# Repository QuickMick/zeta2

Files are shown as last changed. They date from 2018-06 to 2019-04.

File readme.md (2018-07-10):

streaming:
https://www.npmjs.com/package/h264-live-player
https://github.com/131/h264-live-player

old:https://www.npmjs.com/package/raspivid-stream

fan: 0.33 a
GY-88: 0.3 mA

pin input draw (zero position): 0.1 mA

kaufen:IRLML2502
schalter
lötsinn
kabel?
kondensator 47uf, 4.7uf 10uf
0.1uf
470uf
steckbrett

stepper: min 47uf

vllt au den:
IRF3708

crompzange

---------old----------

S8550 -< PNP
https://alltransistors.com/transistor.php?transistor=52917
Maximum Collector-Emitter Voltage |Vce|: 25 V
Maximum Emitter-Base Voltage |Veb|: 5 V
Maximum Collector Current |Ic max|: 0.5 A

S8050 -> TAKE DIS NPN
http://media.nkcelectronics.com/datasheet/s8050.pdf
700ma, 5v

2N5551 
300ma

tkae dis? 2N5401 --> is PNP
600ma

S9013 
0.5a

https://electronics.stackexchange.com/questions/95140/purpose-of-the-diode-and-capacitor-in-this-motor-circuit

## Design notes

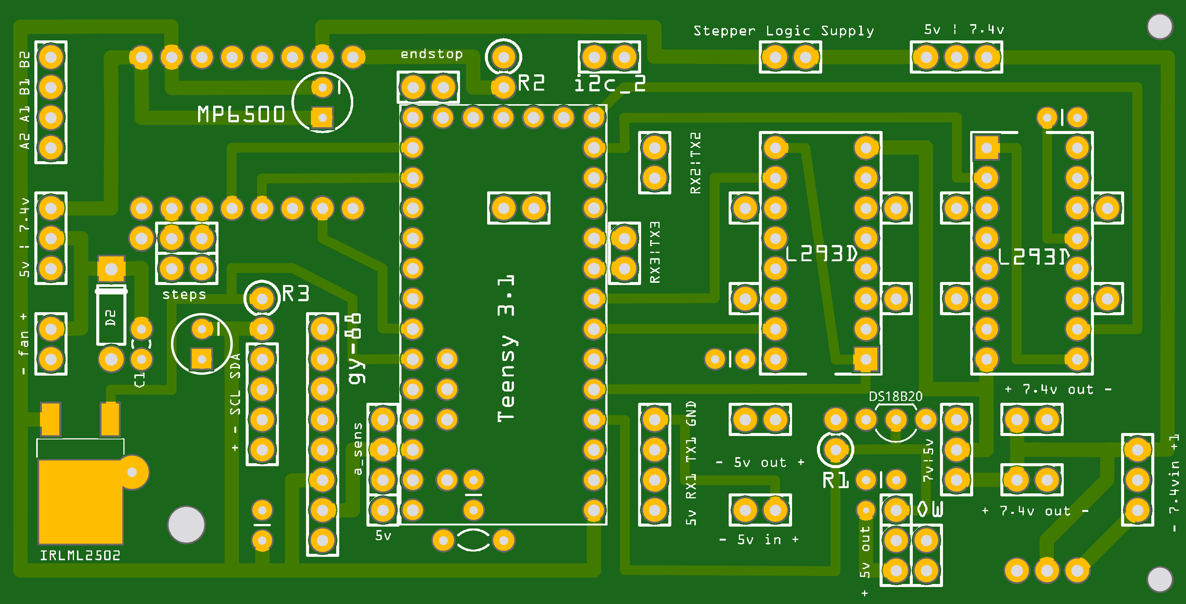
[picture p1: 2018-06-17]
pcb/top.png

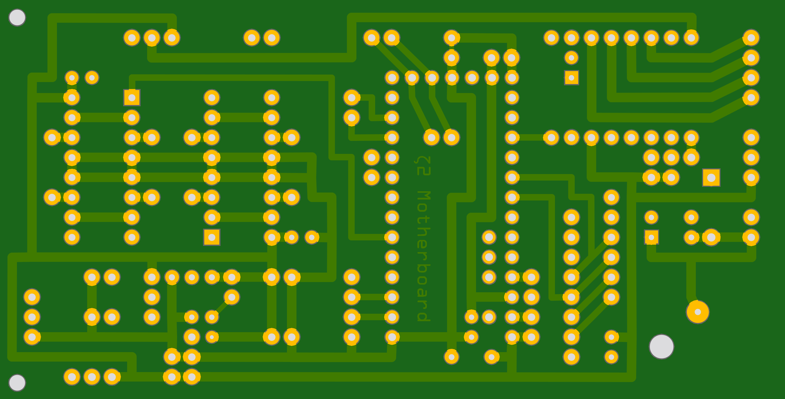
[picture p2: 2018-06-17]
pcb/bottom.png

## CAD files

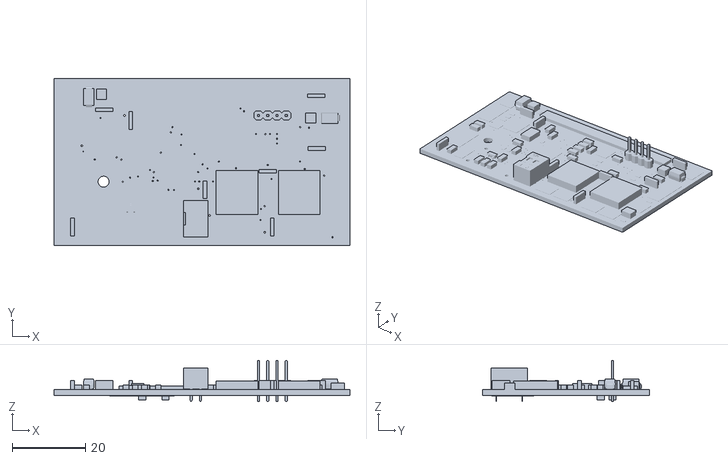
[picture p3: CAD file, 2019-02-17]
pcb/mainboard.stl
81.0 x 45.7 x 11.3

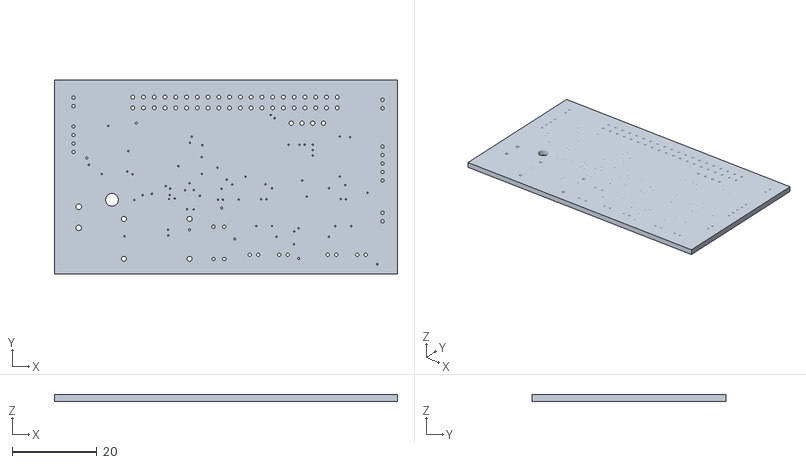
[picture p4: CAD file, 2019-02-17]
pcb/mainboard_pcb.stl
81.0 x 45.7 x 1.57

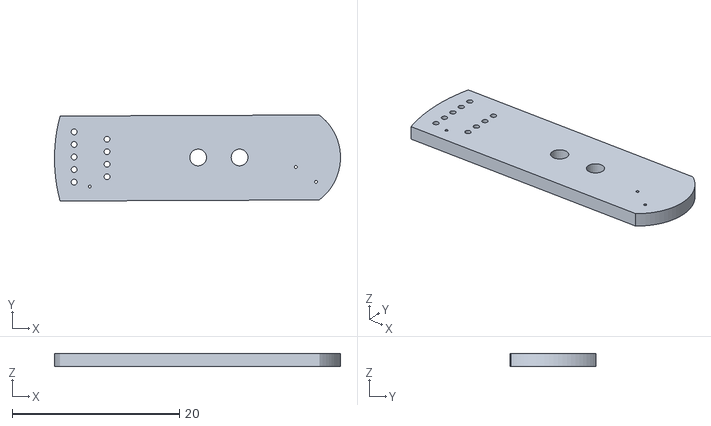
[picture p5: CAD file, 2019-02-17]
pcb/lidar_pcb.stl
34.2 x 10.3 x 1.57

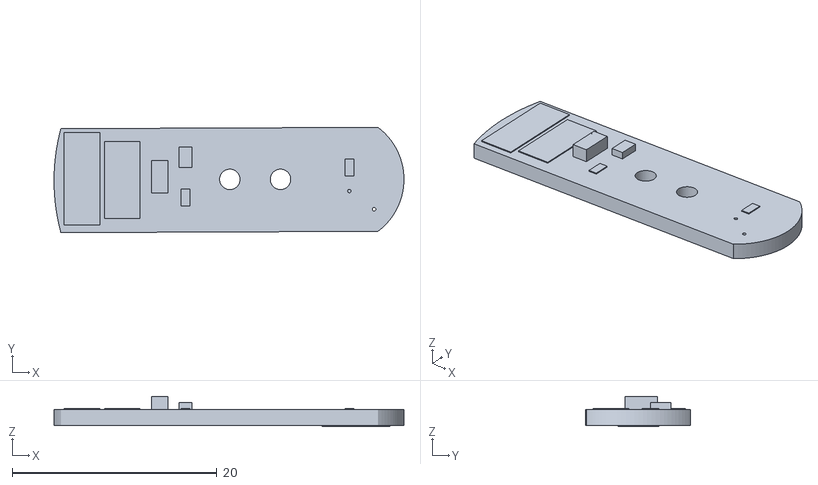
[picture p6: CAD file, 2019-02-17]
pcb/lidar.stl
34.2 x 10.3 x 2.97

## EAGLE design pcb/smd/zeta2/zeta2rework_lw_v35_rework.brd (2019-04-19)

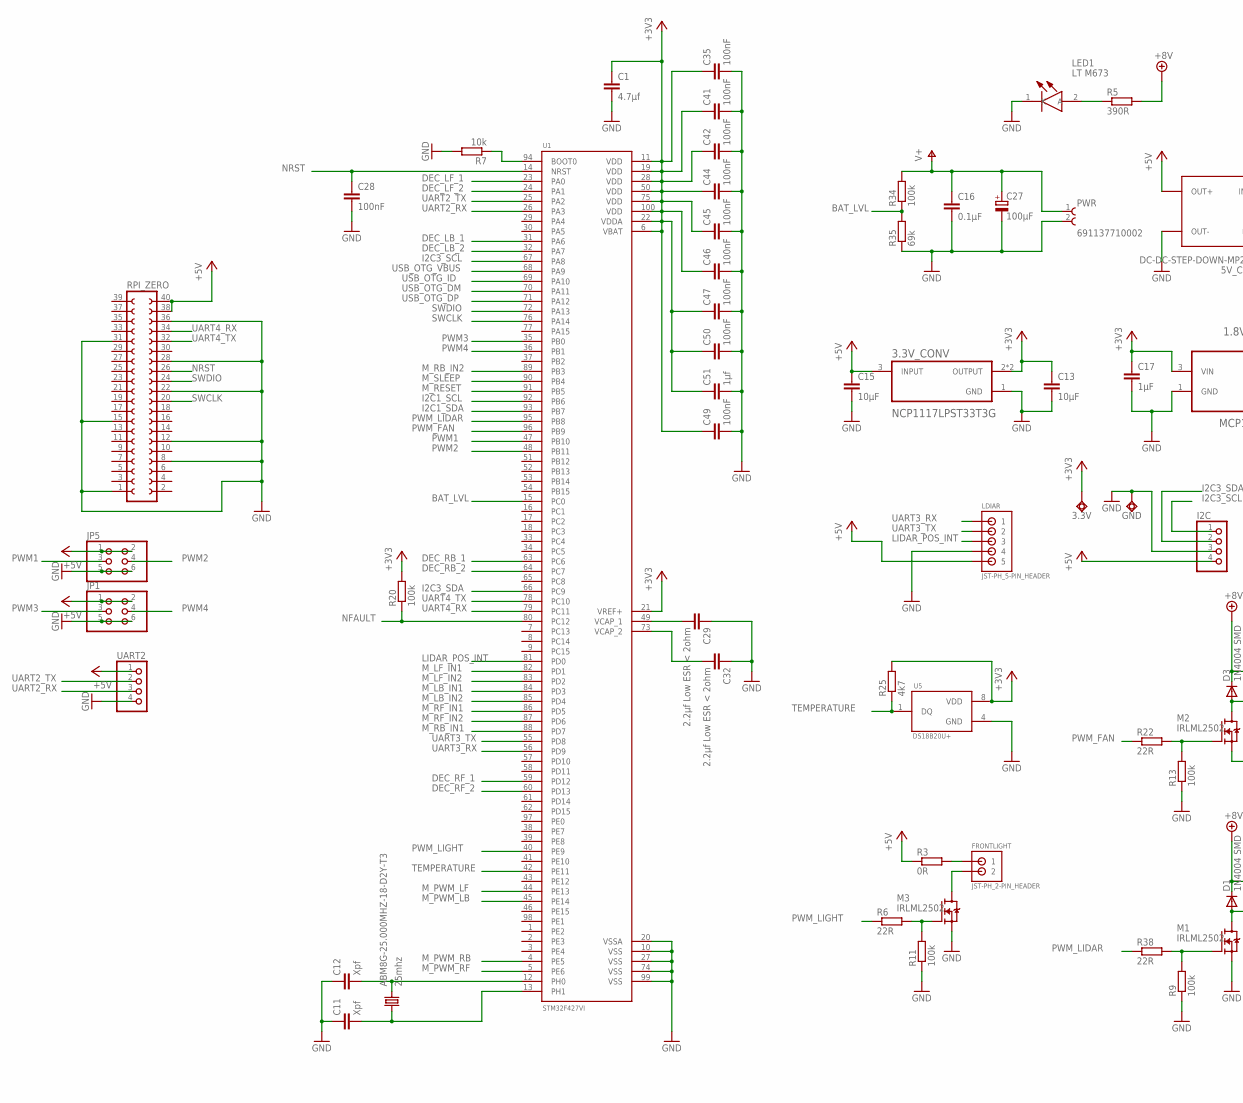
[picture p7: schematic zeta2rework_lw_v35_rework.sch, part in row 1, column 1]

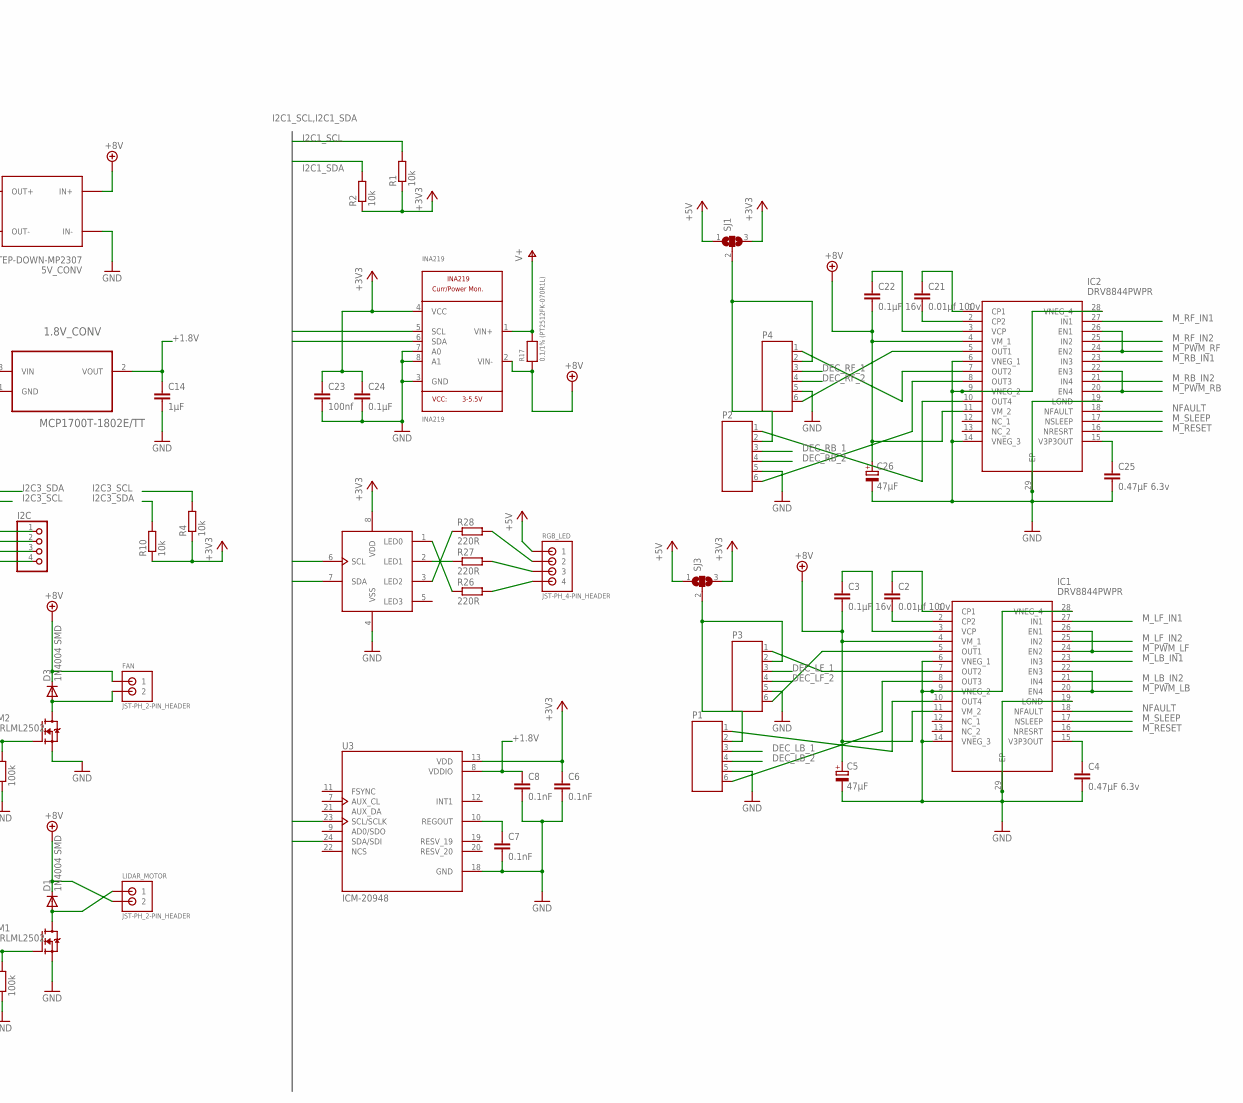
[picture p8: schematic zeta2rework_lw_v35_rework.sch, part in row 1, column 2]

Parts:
1.8V_CONV: MCP1700T-1802E/TT; SOT95P237X112-3N
3.3V: TPSQTP20R; TP20R
3.3V_CONV: NCP1117LPST33T3G; SOT230P700X175-4N
5V_CONV: DC-DC-STEP-DOWN-MP2307
ABM8G-25.000MHZ-18-D2Y-T3: 25mhz; 5.0X3.2_KX-9A
C1: 4.7µf; C0603
C2, C21: 0.01µf 100v; C0603
C3, C22: 0.1µF 16v; C0603
C4, C25: 0.47µF 6.3v; C0603
C5, C26: 47µF; UD-5X5,8_NICHICON
C6, C7, C8: 0.1nF; C0603
C11, C12: Xpf; C0603
C13, C15: 10µF; C1206
C14, C17: 1µF; C0603
C16, C24: 0.1µF; C0603
C23: 100nf; C0603
C27: 100µF; UD-5X5,8_NICHICON
C28, C35, C41, C42, C44, C45, C46, C47, C49, C50: 100nF; C0603
C29, C32: 2.2µf Low ESR < 2ohm; C1206
C51: 1µf; C0603
D1, D3: 1N4004 SMD; DO214AC
FAN: JST-PH_2-PIN_HEADER; JST_B2B-PH_HEADER
FRONTLIGHT: JST-PH_2-PIN_HEADER; JST_B2B-PH_HEADER
GND: TPSQTP20R; TP20R
I2C: PINHD-1X4; 1X04
IC1, IC2: DRV8844PWPR; SOP65P640X120-29N
INA219: INA219; SOT23-8
JP1, JP5: PINHD-2X3; 2X03
LDIAR: JST-PH_5-PIN_HEADER; JST_B5B-PH_HEADER
LED1: LT M673; LTM673-N1R2-25
LIDAR_MOTOR: JST-PH_2-PIN_HEADER; JST_B2B-PH_HEADER
M1, M2, M3: IRLML2502; SOT23
P1, P2, P3, P4: JST-PH6
PCA9533: PCA9533; SOIC8
PWR: 691137710002
R1, R2, R4, R7, R10: 10k; R0603
R3: 0R; R0603
R5: 390R; R0603
R6, R22, R38: 22R; R0603
R9, R11, R13, R20, R34: 100k; R0603
R17: 0.1/1% (PT2512FK-070R1L); 2512
R25: 4k7; R0603
R26, R27, R28: 220R; R0603
R35: 69k; R0603
RGB_LED: JST-PH_4-PIN_HEADER; JST_B4B-PH_HEADER
RPI_ZERO: FE20-2
SJ1, SJ3: SJ2W; SJ_2
U1: STM32F427VI; QFP50P1600X1600X160-100N
U3: ICM-20948; QFN40P300X300X105-25N
U5: DS18B20U+; SOP65P490X95-8N
UART2: PINHD-1X4; 1X04

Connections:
+1.8V: 1.8V_CONV.2 (VOUT), C8.1, C14.1, U3.8 (VDDIO)
+3V3: 1.8V_CONV.3 (VIN), 3.3V.TP, 3.3V_CONV.2 (OUTPUT), 3.3V_CONV.4 (OUTPUT), C1.1, C6.1, C13.1, C17.1, C23.1, C24.1, C35.1, C41.1, C42.1, C44.1, C45.1, C46.1, C47.1, C49.1, C50.1, C51.1, INA219.4 (VCC), PCA9533.8 (VDD), R1.1, R2.1, R4.1, R10.1, R20.2, R25.2, SJ1.3, SJ3.3, U1.6 (VBAT), U1.11 (VDD), U1.19 (VDD), U1.21 (VREF+), U1.22 (VDDA), U1.28 (VDD), U1.50 (VDD), U1.75 (VDD), U1.100 (VDD), U3.13 (VDD), U5.8 (VDD)
+5V: 3.3V_CONV.3 (INPUT), 5V_CONV.OUT+, C15.1, I2C.4, JP1.1, JP1.2, JP5.1, JP5.2, LDIAR.P5 (5), R3.1, RGB_LED.P1 (1), RPI_ZERO.38, RPI_ZERO.40, SJ1.1, SJ3.1, UART2.1
+8V: 5V_CONV.IN+, C3.2, C5.+, C22.2, C26.+, D1.C, D3.C, FAN.P1 (1), IC1.4 (VM_1), IC1.11 (VM_2), IC2.4 (VM_1), IC2.11 (VM_2), INA219.2 (VIN-), LIDAR_MOTOR.P2 (2), R5.2, R17.1
BAT_LVL: R34.1, R35.2, U1.15 (PC0)
DEC_LB_1: P1.3, U1.31 (PA6)
DEC_LB_2: P1.4, U1.32 (PA7)
DEC_LF_1: P3.3, U1.23 (PA0)
DEC_LF_2: P3.4, U1.24 (PA1)
DEC_RB_1: P2.3, U1.63 (PC6)
DEC_RB_2: P2.4, U1.64 (PC7)
DEC_RF_1: P4.3, U1.59 (PD12)
DEC_RF_2: P4.4, U1.60 (PD13)
GND: 1.8V_CONV.1 (GND), 3.3V_CONV.1 (GND), 5V_CONV.IN-, 5V_CONV.OUT-, C1.2, C4.2, C5.-, C6.2, C7.2, C8.2, C11.1, C12.1, C13.2, C14.2, C15.2, C16.2, C17.2, C23.2, C24.2, C25.2, C26.-, C27.-, C28.2, C29.1, C32.1, C35.2, C41.2, C42.2, C44.2, C45.2, C46.2, C47.2, C49.2, C50.2, C51.2, GND.TP, I2C.3, IC1.6 (VNEG_1), IC1.9 (VNEG_2), IC1.14 (VNEG_3), IC1.19 (LGND), IC1.28 (VNEG_4), IC1.29 (EP), IC2.6 (VNEG_1), IC2.9 (VNEG_2), IC2.14 (VNEG_3), IC2.19 (LGND), IC2.28 (VNEG_4), IC2.29 (EP), INA219.3 (GND), INA219.7 (A0), INA219.8 (A1), JP1.5, JP1.6, JP5.5, JP5.6, LDIAR.P4 (4), LED1.1 (K), M1.2 (S), M2.2 (S), M3.2 (S), P1.5, P2.5, P3.5, P4.5, PCA9533.4 (VSS), PWR.2, R7.2, R9.1, R11.1, R13.1, R35.1, RPI_ZERO.1, RPI_ZERO.8, RPI_ZERO.12, RPI_ZERO.15, RPI_ZERO.22, RPI_ZERO.28, RPI_ZERO.31, RPI_ZERO.36, U1.10 (VSS), U1.20 (VSSA), U1.27 (VSS), U1.74 (VSS), U1.99 (VSS), U3.18 (GND), U5.4 (GND), UART2.4
I2C1_SCL: INA219.5 (SCL), PCA9533.6 (SCL), R1.2, U1.92 (PB6), U3.23 (SCL/SCLK)
I2C1_SDA: INA219.6 (SDA), PCA9533.7 (SDA), R2.2, U1.93 (PB7), U3.24 (SDA/SDI)
I2C3_SCL: I2C.1, R4.2, U1.67 (PA8)
I2C3_SDA: I2C.2, R10.2, U1.66 (PC9)
LIDAR_POS_INT: LDIAR.P3 (3), U1.81 (PD0)
M_LB_IN1: IC1.23 (IN3), U1.84 (PD3)
M_LB_IN2: IC1.21 (IN4), U1.85 (PD4)
M_LF_IN1: IC1.27 (IN1), U1.82 (PD1)
M_LF_IN2: IC1.25 (IN2), U1.83 (PD2)
M_PWM_LB: IC1.20 (EN4), IC1.22 (EN3), U1.45 (PE14)
M_PWM_LF: IC1.24 (EN2), IC1.26 (EN1), U1.44 (PE13)
M_PWM_RB: IC2.20 (EN4), IC2.22 (EN3), U1.4 (PE5)
M_PWM_RF: IC2.24 (EN2), IC2.26 (EN1), U1.5 (PE6)
M_RB_IN1: IC2.23 (IN3), U1.88 (PD7)
M_RB_IN2: IC2.21 (IN4), U1.89 (PB3)
M_RESET: IC1.16 (NRESRT), IC2.16 (NRESRT), U1.91 (PB5)
M_RF_IN1: IC2.27 (IN1), U1.86 (PD5)
M_RF_IN2: IC2.25 (IN2), U1.87 (PD6)
M_SLEEP: IC1.17 (NSLEEP), IC2.17 (NSLEEP), U1.90 (PB4)
unnamed: C21.2, IC2.2 (CP2)
unnamed: C21.1, IC2.1 (CP1)
unnamed: C22.1, IC2.3 (VCP)
unnamed: IC2.10 (OUT4), P2.1
unnamed: FRONTLIGHT.P1 (1), R3.2
unnamed: LED1.2 (A), R5.1
unnamed: C7.1, U3.10 (REGOUT)
unnamed: FRONTLIGHT.P2 (2), M3.3 (D)
unnamed: M3.1 (G), R6.2, R11.2
unnamed: IC2.5 (OUT1), P4.6
unnamed: IC2.7 (OUT2), P4.1
unnamed: ABM8G-25.000MHZ-18-D2Y-T3.1, C11.2, U1.13 (PH1)
unnamed: IC1.5 (OUT1), P3.6
unnamed: R7.1, U1.94 (BOOT0)
unnamed: C2.2, IC1.2 (CP2)
unnamed: IC2.8 (OUT3), P2.6
unnamed: C2.1, IC1.1 (CP1)
unnamed: C3.1, IC1.3 (VCP)
unnamed: PCA9533.1 (LED0), R26.1
unnamed: PCA9533.2 (LED1), R27.1
unnamed: PCA9533.3 (LED2), R28.1
unnamed: C25.1, IC2.15 (V3P3OUT)
unnamed: IC1.7 (OUT2), P3.1
unnamed: IC1.8 (OUT3), P1.6
unnamed: C4.1, IC1.15 (V3P3OUT)
unnamed: IC1.10 (OUT4), P1.1
unnamed: R26.2, RGB_LED.P4 (4)
unnamed: P2.2, P4.2, SJ1.2
unnamed: R27.2, RGB_LED.P3 (3)
unnamed: R28.2, RGB_LED.P2 (2)
unnamed: C29.2, U1.49 (VCAP_1)
unnamed: M2.1 (G), R13.2, R22.2
unnamed: M1.1 (G), R9.2, R38.2
unnamed: D1.A, LIDAR_MOTOR.P1 (1), M1.3 (D)
unnamed: P1.2, P3.2, SJ3.2
unnamed: ABM8G-25.000MHZ-18-D2Y-T3.3 (2), C12.2, U1.12 (PH0)
unnamed: C32.2, U1.73 (VCAP_2)
unnamed: D3.A, FAN.P2 (2), M2.3 (D)
NFAULT: IC1.18 (NFAULT), IC2.18 (NFAULT), R20.1, U1.80 (PC12)
NRST: C28.1, RPI_ZERO.26, U1.14 (NRST)
PWM1: JP5.3, U1.47 (PB10)
PWM2: JP5.4, U1.48 (PB11)
PWM3: JP1.3, U1.35 (PB0)
PWM4: JP1.4, U1.36 (PB1)
PWM_FAN: R22.1, U1.96 (PB9)
PWM_LIDAR: R38.1, U1.95 (PB8)
PWM_LIGHT: R6.1, U1.40 (PE9)
SWCLK: RPI_ZERO.20, U1.76 (PA14)
SWDIO: RPI_ZERO.24, U1.72 (PA13)
TEMPERATURE: R25.1, U1.42 (PE11), U5.1 (DQ)
UART2_RX: U1.26 (PA3), UART2.3
UART2_TX: U1.25 (PA2), UART2.2
UART3_RX: LDIAR.P1 (1), U1.56 (PD9)
UART3_TX: LDIAR.P2 (2), U1.55 (PD8)
UART4_RX: RPI_ZERO.34, U1.79 (PC11)
UART4_TX: RPI_ZERO.32, U1.78 (PC10)
USB_OTG_DM: U1.70 (PA11)
USB_OTG_DP: U1.71 (PA12)
USB_OTG_ID: U1.69 (PA10)
USB_OTG_VBUS: U1.68 (PA9)
V+: C16.1, C27.+, INA219.1 (VIN+), PWR.1, R17.2, R34.2

Board: 4 copper layers, 92 parts (6 on the bottom side), 90 nets, no tracks yet.

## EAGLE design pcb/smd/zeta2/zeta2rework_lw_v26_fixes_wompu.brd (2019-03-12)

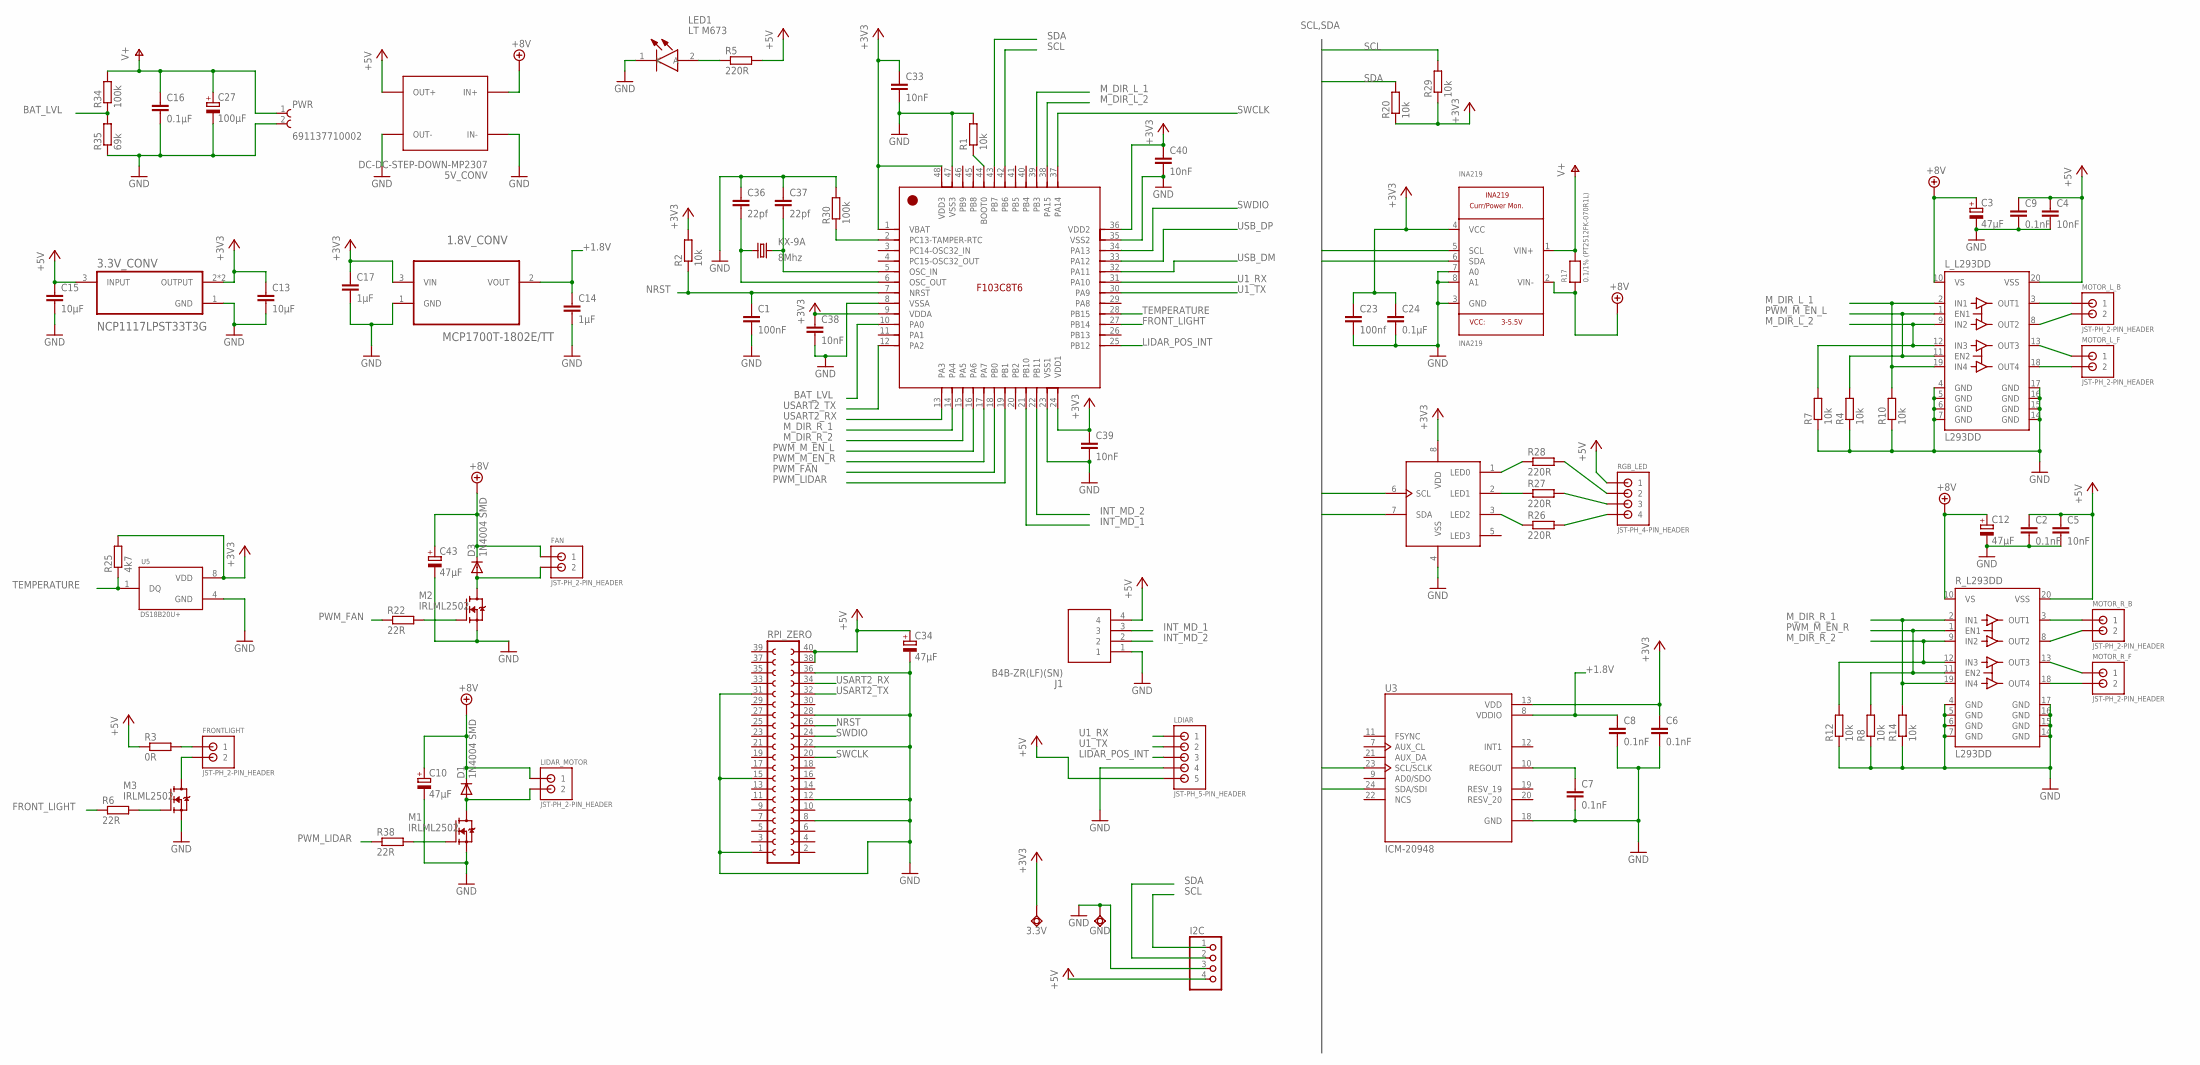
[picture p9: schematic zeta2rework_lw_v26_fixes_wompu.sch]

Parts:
1.8V_CONV: MCP1700T-1802E/TT; SOT95P237X112-3N
3.3V: TPSQTP20R; TP20R
3.3V_CONV: NCP1117LPST33T3G; SOT230P700X175-4N
5V_CONV: DC-DC-STEP-DOWN-MP2307
C1: 100nF; C1206
C2, C6, C7, C8, C9: 0.1nF; C1206
C3, C10, C12, C34, C43: 47µF; UD-5X5,8_NICHICON
C4, C5, C33, C38, C39, C40: 10nF; C1206
C13, C15: 10µF; C1206
C14, C17: 1µF; C1206
C16, C24: 0.1µF; C1206
C23: 100nf; C1206
C27: 100µF; UD-5X5,8_NICHICON
C36, C37: 22pf; C1206
D1, D3: 1N4004 SMD; DO214AC
FAN: JST-PH_2-PIN_HEADER; JST_B2B-PH_HEADER
FRONTLIGHT: JST-PH_2-PIN_HEADER; JST_B2B-PH_HEADER
GND: TPSQTP20R; TP20R
I2C: PINHD-1X4; 1X04
INA219: INA219; SOT23-8
J1: B4B-ZR(LF)(SN); SHDR4W50P0X150_1X4_750X350X450
KX-9A: 8Mhz; 5.0X3.2_KX-9A
LDIAR: JST-PH_5-PIN_HEADER; JST_B5B-PH_HEADER
LED1: LT M673; LTM673-N1R2-25
LIDAR_MOTOR: JST-PH_2-PIN_HEADER; JST_B2B-PH_HEADER
L_L293DD: L293DD; SO20
M1, M2, M3: IRLML2502; SOT23
MOTOR_L_B: JST-PH_2-PIN_HEADER; JST_B2B-PH_HEADER
MOTOR_L_F: JST-PH_2-PIN_HEADER; JST_B2B-PH_HEADER
MOTOR_R_B: JST-PH_2-PIN_HEADER; JST_B2B-PH_HEADER
MOTOR_R_F: JST-PH_2-PIN_HEADER; JST_B2B-PH_HEADER
PCA9533: PCA9533; SOIC8
PWR: 691137710002
R1, R2, R4, R7, R8, R10, R12, R14, R20, R29: 10k; R0603
R3: 0R; R0603
R5, R26, R27, R28: 220R; R0603
R6, R22, R38: 22R; R0603
R17: 0.1/1% (PT2512FK-070R1L); 2512
R25: 4k7; R0603
R30, R34: 100k; R0603
R35: 69k; R0603
RGB_LED: JST-PH_4-PIN_HEADER; JST_B4B-PH_HEADER
RPI_ZERO: FE20-2
R_L293DD: L293DD; SO20
STM32F103CB: STM32F103CB; LQFP48_7X7MM_0.5MMPP
U3: ICM-20948; QFN40P300X300X105-25N
U5: DS18B20U+; SOP65P490X95-8N

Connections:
+1.8V: 1.8V_CONV.2 (VOUT), C8.1, C14.1, U3.8 (VDDIO)
+3V3: 1.8V_CONV.3 (VIN), 3.3V.TP, 3.3V_CONV.2 (OUTPUT), 3.3V_CONV.4 (OUTPUT), C6.1, C13.1, C17.1, C23.1, C24.1, C33.1, C38.1, C39.1, C40.1, INA219.4 (VCC), PCA9533.8 (VDD), R2.2, R20.1, R25.2, R29.1, STM32F103CB.1 (VBAT), STM32F103CB.9 (VDDA), STM32F103CB.24 (VDD1), STM32F103CB.36 (VDD2), STM32F103CB.48 (VDD3), U3.13 (VDD), U5.8 (VDD)
+5V: 3.3V_CONV.3 (INPUT), 5V_CONV.OUT+, C2.1, C4.1, C5.1, C9.1, C15.1, C34.+, I2C.4, J1.4, LDIAR.P5 (5), L_L293DD.20 (VSS), R3.1, R5.2, RGB_LED.P1 (1), RPI_ZERO.38, RPI_ZERO.40, R_L293DD.20 (VSS)
+8V: 5V_CONV.IN+, C3.+, C10.+, C12.+, C43.+, D1.C, D3.C, FAN.P1 (1), INA219.2 (VIN-), LIDAR_MOTOR.P1 (1), L_L293DD.10 (VS), R17.1, R_L293DD.10 (VS)
BAT_LVL: R34.1, R35.2, STM32F103CB.10 (PA0)
FRONT_LIGHT: R6.1, STM32F103CB.27 (PB14)
GND: 1.8V_CONV.1 (GND), 3.3V_CONV.1 (GND), 5V_CONV.IN-, 5V_CONV.OUT-, C1.2, C2.2, C3.-, C4.2, C5.2, C6.2, C7.2, C8.2, C9.2, C10.-, C12.-, C13.2, C14.2, C15.2, C16.2, C17.2, C23.2, C24.2, C27.-, C33.2, C34.-, C36.1, C37.1, C38.2, C39.2, C40.2, C43.-, GND.TP, I2C.3, INA219.3 (GND), INA219.7 (A0), INA219.8 (A1), J1.1, LDIAR.P4 (4), LED1.1 (K), L_L293DD.4 (GND), L_L293DD.5 (GND), L_L293DD.6 (GND), L_L293DD.7 (GND), L_L293DD.14 (GND), L_L293DD.15 (GND), L_L293DD.16 (GND), L_L293DD.17 (GND), M1.2 (S), M2.2 (S), M3.2 (S), PCA9533.4 (VSS), PWR.2, R1.2, R4.1, R7.1, R8.1, R10.1, R12.1, R14.1, R30.2, R35.1, RPI_ZERO.1, RPI_ZERO.8, RPI_ZERO.12, RPI_ZERO.15, RPI_ZERO.22, RPI_ZERO.28, RPI_ZERO.31, RPI_ZERO.36, R_L293DD.4 (GND), R_L293DD.5 (GND), R_L293DD.6 (GND), R_L293DD.7 (GND), R_L293DD.14 (GND), R_L293DD.15 (GND), R_L293DD.16 (GND), R_L293DD.17 (GND), STM32F103CB.8 (VSSA), STM32F103CB.23 (VSS1), STM32F103CB.35 (VSS2), STM32F103CB.47 (VSS3), U3.18 (GND), U5.4 (GND)
INT_MD_1: J1.3, STM32F103CB.21 (PB10)
INT_MD_2: J1.2, STM32F103CB.22 (PB11)
LIDAR_POS_INT: LDIAR.P3 (3), STM32F103CB.25 (PB12)
M_DIR_L_1: L_L293DD.2 (IN1), L_L293DD.19 (IN4), R10.2, STM32F103CB.39 (PB3)
M_DIR_L_2: L_L293DD.9 (IN2), L_L293DD.12 (IN3), R7.2, STM32F103CB.38 (PA15)
M_DIR_R_1: R14.2, R_L293DD.2 (IN1), R_L293DD.19 (IN4), STM32F103CB.14 (PA4)
M_DIR_R_2: R12.2, R_L293DD.9 (IN2), R_L293DD.12 (IN3), STM32F103CB.15 (PA5)
unnamed: MOTOR_R_B.P2 (2), R_L293DD.8 (OUT2)
unnamed: MOTOR_R_F.P2 (2), R_L293DD.18 (OUT4)
unnamed: MOTOR_R_F.P1 (1), R_L293DD.13 (OUT3)
unnamed: L_L293DD.18 (OUT4), MOTOR_L_F.P2 (2)
unnamed: R1.1, STM32F103CB.44 (BOOT0)
unnamed: FRONTLIGHT.P1 (1), R3.2
unnamed: LED1.2 (A), R5.1
unnamed: C7.1, U3.10 (REGOUT)
unnamed: FRONTLIGHT.P2 (2), M3.3 (D)
unnamed: M3.1 (G), R6.2
unnamed: L_L293DD.13 (OUT3), MOTOR_L_F.P1 (1)
unnamed: L_L293DD.8 (OUT2), MOTOR_L_B.P2 (2)
unnamed: L_L293DD.3 (OUT1), MOTOR_L_B.P1 (1)
unnamed: PCA9533.3 (LED2), R26.1
unnamed: PCA9533.2 (LED1), R27.1
unnamed: PCA9533.1 (LED0), R28.1
unnamed: MOTOR_R_B.P1 (1), R_L293DD.3 (OUT1)
unnamed: R26.2, RGB_LED.P4 (4)
unnamed: R27.2, RGB_LED.P3 (3)
unnamed: R28.2, RGB_LED.P2 (2)
unnamed: M2.1 (G), R22.2
unnamed: M1.1 (G), R38.2
unnamed: D1.A, LIDAR_MOTOR.P2 (2), M1.3 (D)
unnamed: C36.2, KX-9A.1, STM32F103CB.6 (OSC_OUT)
unnamed: C37.2, KX-9A.3 (2), STM32F103CB.5 (OSC_IN)
unnamed: R30.1, STM32F103CB.2 (PC13-TAMPER-RTC)
unnamed: D3.A, FAN.P2 (2), M2.3 (D)
NRST: C1.1, R2.1, RPI_ZERO.26, STM32F103CB.7 (NRST)
PWM_FAN: R22.1, STM32F103CB.18 (PB0)
PWM_LIDAR: R38.1, STM32F103CB.19 (PB1)
PWM_M_EN_L: L_L293DD.1 (EN1), L_L293DD.11 (EN2), R4.2, STM32F103CB.16 (PA6)
PWM_M_EN_R: R8.2, R_L293DD.1 (EN1), R_L293DD.11 (EN2), STM32F103CB.17 (PA7)
SCL: I2C.1, INA219.5 (SCL), PCA9533.6 (SCL), R29.2, STM32F103CB.42 (PB6), U3.23 (SCL/SCLK)
SDA: I2C.2, INA219.6 (SDA), PCA9533.7 (SDA), R20.2, STM32F103CB.43 (PB7), U3.24 (SDA/SDI)
SWCLK: RPI_ZERO.20, STM32F103CB.37 (PA14)
SWDIO: RPI_ZERO.24, STM32F103CB.34 (PA13)
TEMPERATURE: R25.1, STM32F103CB.28 (PB15), U5.1 (DQ)
U1_RX: LDIAR.P1 (1), STM32F103CB.31 (PA10)
U1_TX: LDIAR.P2 (2), STM32F103CB.30 (PA9)
USART2_RX: RPI_ZERO.34, STM32F103CB.13 (PA3)
USART2_TX: RPI_ZERO.32, STM32F103CB.12 (PA2)
USB_DM: STM32F103CB.32 (PA11)
USB_DP: STM32F103CB.33 (PA12)
V+: C16.1, C27.+, INA219.1 (VIN+), PWR.1, R17.2, R34.2

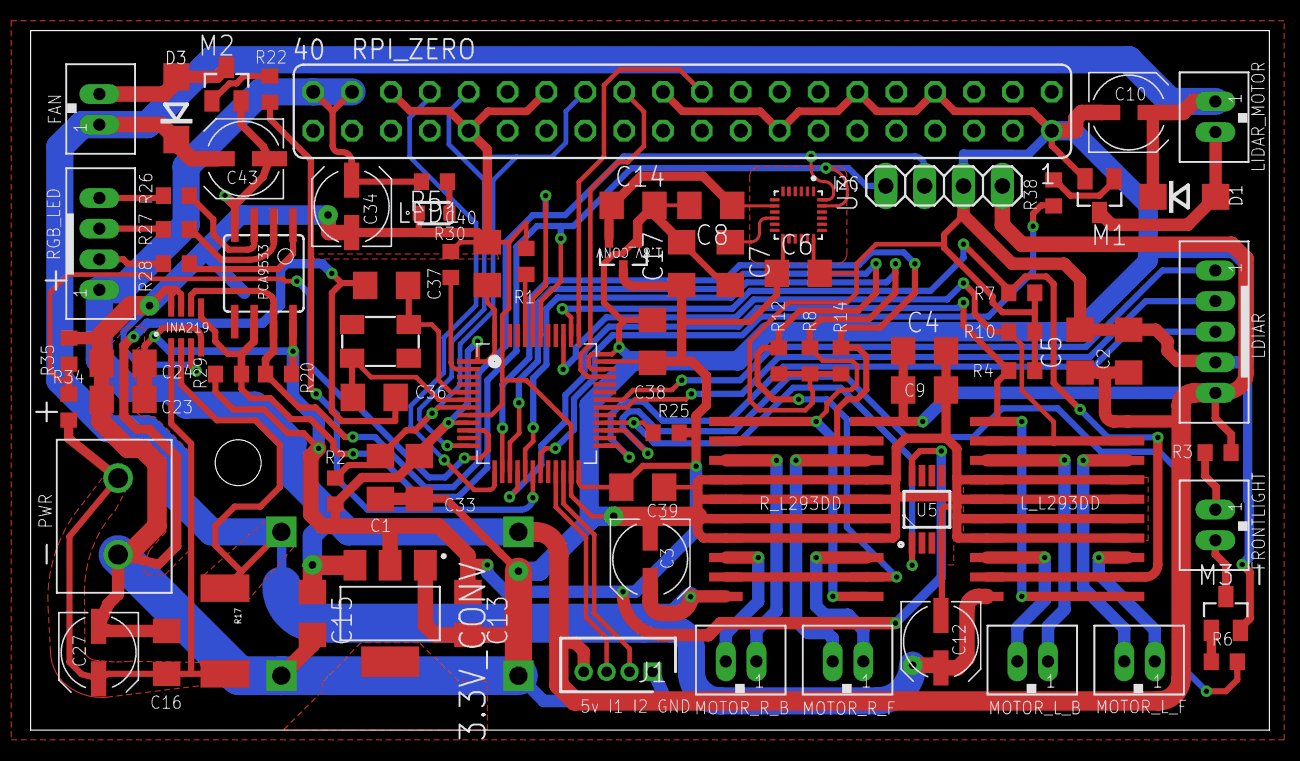
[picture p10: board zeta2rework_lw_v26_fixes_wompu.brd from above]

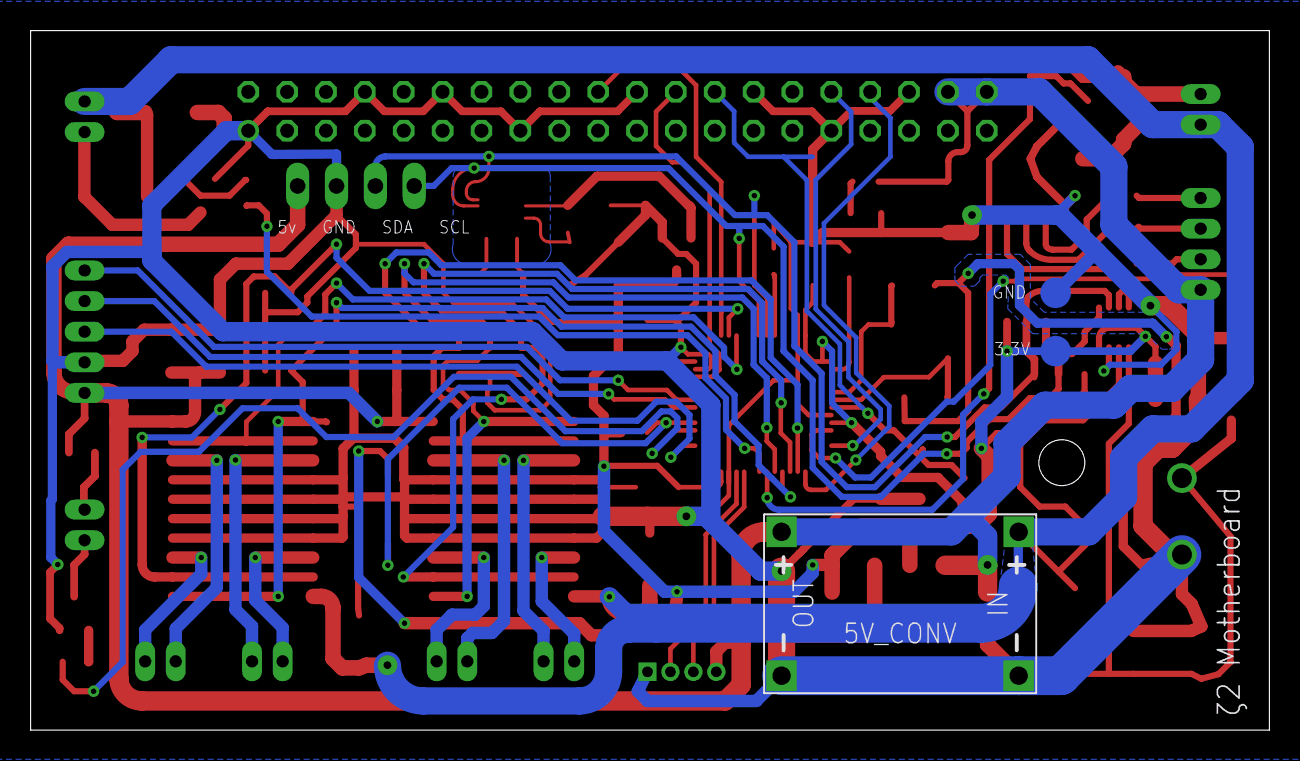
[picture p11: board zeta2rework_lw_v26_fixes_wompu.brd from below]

Board: 2 copper layers, 81.0 x 45.7 mm, 82 parts (3 on the bottom side), 56 nets.

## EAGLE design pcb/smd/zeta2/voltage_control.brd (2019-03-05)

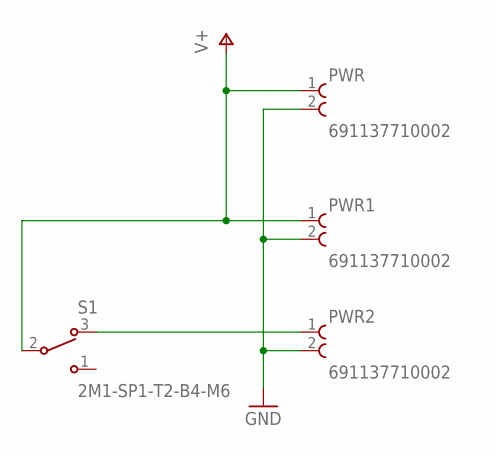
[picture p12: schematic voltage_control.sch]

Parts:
PWR, PWR1, PWR2: 691137710002
S1: 2M1-SP1-T2-B4-M6

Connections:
GND: PWR.2, PWR1.2, PWR2.2
unnamed: PWR2.1, S1.3 (O)
V+: PWR.1, PWR1.1, S1.2

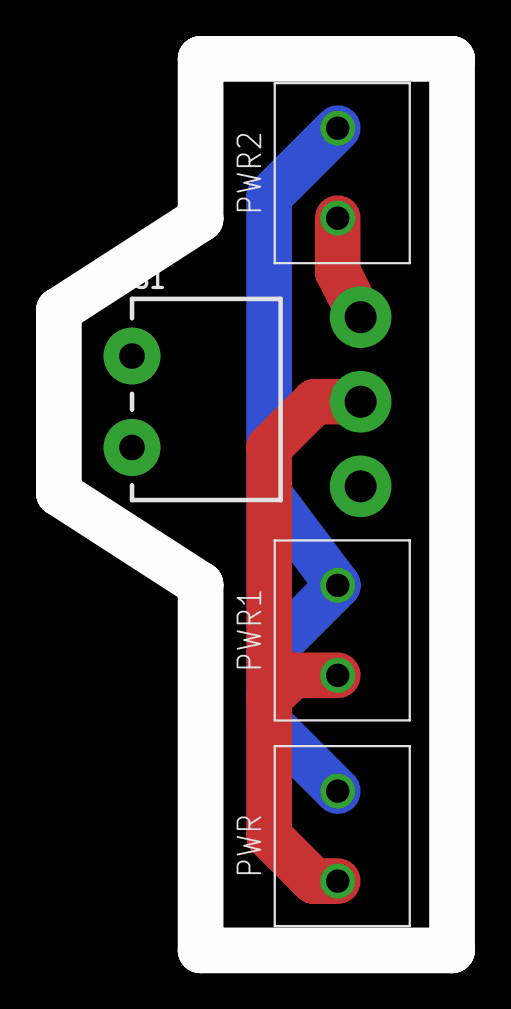
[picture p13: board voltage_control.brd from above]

Board: 2 copper layers, 21.8 x 49.5 mm, 4 parts (0 on the bottom side), 3 nets.

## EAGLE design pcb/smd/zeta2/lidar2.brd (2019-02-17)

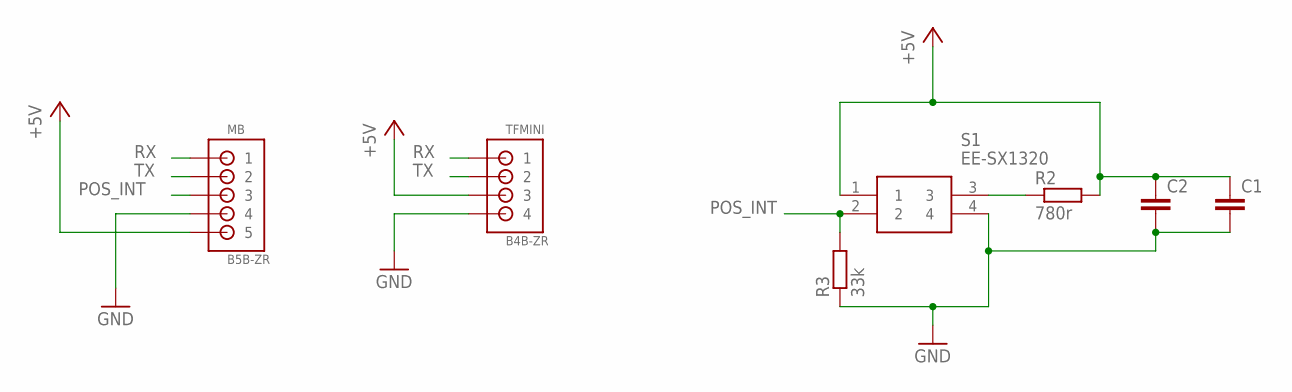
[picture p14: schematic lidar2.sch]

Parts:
C1: C-EUC1206; C1206
C2: C-EUC0805; C0805
MB: B5B-ZR
R2: 780r; R0603
R3: 33k; R0603
S1: EE-SX1320
TFMINI: B4B-ZR

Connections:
+5V: C1.1, C2.1, MB.5, R2.2, S1.1, TFMINI.3
GND: C1.2, C2.2, MB.4, R3.1, S1.4, TFMINI.4
unnamed: R2.1, S1.3
POS_INT: MB.3, R3.2, S1.2
RX: MB.1, TFMINI.1
TX: MB.2, TFMINI.2

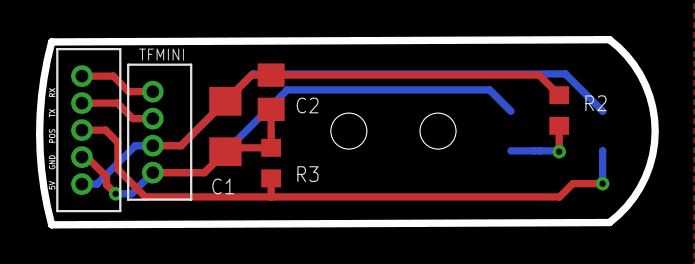
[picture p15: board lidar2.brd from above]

Board: 2 copper layers, 34.2 x 10.3 mm, 7 parts (1 on the bottom side), 6 nets.

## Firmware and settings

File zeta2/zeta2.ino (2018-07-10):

#include <Wire.h>
#include <TeensyThreads.h>
#include <OneWire.h>
#include <DallasTemperature.h>
#include "pins.h"
#include "stepper.h"
#include "motor.h"
#include "fan.h"
#include "BMP085.h"
#include "I2Cdev.h"
#include "MPU6050.h"
#include "TFMini.h"

BMP085 pressure_m;
MPU6050 accelgyro;  
TFMini tfmini;

//Stepper lidarStepper(PIN_STEPPER_0, PIN_STEPPER_1, PIN_STEPPER_2, PIN_STEPPER_3);
Motor motorLeft(PIN_MOTOR_LEFT_A, PIN_MOTOR_LEFT_B, PIN_ENABLE_LEFT);
Motor motorRight(PIN_MOTOR_RIGHT_A, PIN_MOTOR_RIGHT_B, PIN_ENABLE_RIGHT);
Fan fan(PIN_FAN);

OneWire ds(PIN_MOTOR_TEMPERATURE);
DallasTemperature sensors(&ds);
DeviceAddress insideThermometer = {0x28, 0x61, 0x64, 0x11, 0xBD, 0x93, 0xD5, 0x1};

/*
gelb: gyp-distance-sensor
braun: zero-position-sensor
grün: grün von tfmini distance-sensor tx
orange: weiß von tfmini distance-sensor rx
*/

/*
 1,1 ma alle 4motoren+stepper+fan
23ma teensy
*/
byte addr[8];
void setup()
{
  Serial.begin(9600);    // debug serial
  Serial1.begin(115200); // TFMINI serial
  Wire.begin();          // I2C

  // wait till serial is here
  while (!Serial && !Serial1)
  {
  }

  tfmini.begin(&Serial1);

  /**
   *  configure OUTPUT pins
   */
  fan.begin();
 // lidarStepper.begin();
  motorLeft.begin();
  motorRight.begin();

  /**
   *  configure INPUT pins
   */
  pinMode(PIN_ZEROING_SENSOR, INPUT);
  pinMode(PIN_ANALOG_DISTANCE, INPUT);

  /**
   * Start Sensor connections
   */
  Serial.println("Initializing I2C devices...");
  accelgyro.initialize();
  // verify connection
  Serial.println("Testing device connections...");
  Serial.println(accelgyro.testConnection() ? "MPU6050 connection successful" : "MPU6050 connection failed");
  pressure_m.bmp085Calibration();

  /**
   * Start Threads
   */
 //  threads.addThread(blinkthread);
  // threads.addThread(stepMotorTest);
  /*
  ds.search(addr);

  Serial.print("R=");
  for (int i = 0; i < 8; i++)
  {
    Serial.print(addr[i], HEX);
    Serial.print(" ");
  }

  if (OneWire::crc8(addr, 7) != addr[7])
  {
    Serial.print("CRC is not valid!\n");
    return;
  }

  ds.select(addr);
  ds.write(0x44, 1); // start conversion, with parasite power on at the end
  delay(1000);
  ds.reset();
  ds.select(addr);
  ds.write(0xBE); // Read Scratchpad
  */
  sensors.begin();
  sensors.setResolution(insideThermometer, 9);
  if (sensors.isParasitePowerMode())
    Serial.println("Dallas ParasitePower: ON");
  else
    Serial.println("Dallas ParasitePower: OFF");
  if (!sensors.getAddress(insideThermometer, 0))
    Serial.println("Unable to find address for Device 0");
}

void loop()
{

//analogRead(PIN_ZEROING_SENSOR);
  
  //lidarStepper.next();
  

  Serial.print(" Requesting temperatures...");
  int x = millis();
  sensors.requestTemperatures(); // Send the command to get temperature readings
  int x2 = millis();

  Serial.print("Temperature is: ");
  Serial.print(sensors.getTempC(insideThermometer)); //sensors.getTempCByIndex(0)); // Why "byIndex"?
  Serial.print("    time:");
  Serial.print(x2 - x);
  // You can have more than one DS18B20 on the same bus.
  // 0 refers to the first IC on the wire

  Serial.println("  DONE");
  delay(1000);


  int16_t ax, ay, az;
  int16_t gx, gy, gz;
  float temperature;
  float pressure;
  float altitude;



    temperature = pressure_m.bmp085GetTemperature(); //MUST be called first
    pressure = pressure_m.bmp085GetPressure();
    altitude = pressure_m.calcAltitude(pressure);
    accelgyro.getMotion6(&ax, &ay, &az, &gx, &gy, &gz);
    motorLeft.set(255);
    motorRight.set(255);
    fan.update(1000);

    Serial.print("ZEROING: ");
    Serial.print(digitalRead(PIN_ZEROING_SENSOR));
    Serial.println();
    Serial.print("Temperature: ");
    Serial.print(temperature, 2); //display 2 decimal places
    Serial.println("deg C");

    Serial.print("Pressure: ");
    Serial.print(pressure, 0); //whole number only.
    Serial.println(" Pa");

    Serial.print("Altitude: ");
    Serial.print(altitude, 2); //display 2 decimal places
    Serial.println(" M");

    Serial.println(); //line break

    // display tab-separated accel/gyro x/y/z values
    Serial.print("a/g:\t");
    Serial.print(ax);
    Serial.print("\t");
    Serial.print(ay);
    Serial.print("\t");
    Serial.print(az);
    Serial.print("\t");
    Serial.print(gx);
    Serial.print("\t");
    Serial.print(gy);
    Serial.print("\t");
    Serial.println(gz);
  
}

void stepMotorTest()
{
  while (1)
  {
    Serial.print(millis());
    Serial.print(" ");
    Serial.print("R=");
    for (int i = 0; i < 8; i++)
    {
      Serial.print(addr[i], HEX);
      Serial.print(" ");
    }

    Serial.println(" ");
    delay(1000);
    threads.delay(50);

    /*  for(int i=0;i<256;i++){
    lidarStepper.next();
    delay(1);
    }*/
    /*  Serial.print(millis());
    Serial.print("STEP ");
   
    Serial.print(lidarStepper.currentStep);*/
  }
}

void blinkthread()
{

  int16_t ax, ay, az;
  int16_t gx, gy, gz;
  float temperature;
  float pressure;
  float altitude;
  byte data[12];

  while (1)
  {
    Serial.print("P=");
    for (int i = 0; i < 9; i++)
    { // we need 9 bytes
      data[i] = ds.read();
      Serial.print(data[i], HEX);
      Serial.print(" ");
    }
    Serial.print(" CRC=");
    Serial.print(OneWire::crc8(data, 8), HEX);
    Serial.println();

    temperature = pressure_m.bmp085GetTemperature(); //MUST be called first
    pressure = pressure_m.bmp085GetPressure();
    altitude = pressure_m.calcAltitude(pressure);
    accelgyro.getMotion6(&ax, &ay, &az, &gx, &gy, &gz);
    motorLeft.set(255);
    motorRight.set(255);
    fan.update(1000);

    Serial.print("ZEROING: ");
    Serial.print(digitalRead(PIN_ZEROING_SENSOR));
    Serial.println();

    /* digitalWrite(LED, HIGH);
    threads.delay(150);
    digitalWrite(LED, LOW);
    threads.delay(150);*/

    // threads.yield();

    uint16_t dist = tfmini.getDistance();
    uint16_t strength = tfmini.getRecentSignalStrength();
    // Display the measurement
    Serial.print(dist);
    Serial.print(" cm      sigstr: ");
    Serial.println(strength);

    Serial.print("Temperature: ");
    Serial.print(temperature, 2); //display 2 decimal places
    Serial.println("deg C");

    Serial.print("Pressure: ");
    Serial.print(pressure, 0); //whole number only.
    Serial.println(" Pa");

    Serial.print("Altitude: ");
    Serial.print(altitude, 2); //display 2 decimal places
    Serial.println(" M");

    Serial.println(); //line break

    // display tab-separated accel/gyro x/y/z values
    Serial.print("a/g:\t");
    Serial.print(ax);
    Serial.print("\t");
    Serial.print(ay);
    Serial.print("\t");
    Serial.print(az);
    Serial.print("\t");
    Serial.print(gx);
    Serial.print("\t");
    Serial.print(gy);
    Serial.print("\t");
    Serial.println(gz);

    threads.delay(500);
  }
}

void motorcontrol()
{
}

void controllLIDAR()
{
}

void readCommands()
{
}

/*
#include <Arduino.h>


const int LED = 13;

volatile int blinkcode = 0;

void blinkthread() {
  while(1) {
    if (blinkcode) {
      for (int i=0; i<blinkcode; i++) {
        digitalWrite(LED, HIGH);
        threads.delay(150);
        digitalWrite(LED, LOW);
        threads.delay(150);
      }
      blinkcode = 0;
    }
    threads.yield();
  }
}

void setup() {
  delay(1000);
  pinMode(LED, OUTPUT);
  threads.addThread(blinkthread);
}

int count = 0;

void loop() {
  count++;
  blinkcode = count;
  delay(5000);
}
*/

/*
#include <TeensyThreads.h>

volatile long int count = 0;

void thread_func(int inc) {
  while(1) count += inc;
}

void setup() {
  threads.addThread(thread_func, 1);
}

void loop() {
  Serial.println(count);
  threads.delay(1000);
}*/

/*
 * 
 * #include "SoftwareSerial.h"

#include "TFMini.h"


// Setup software serial port

SoftwareSerial mySerial(10, 11);      // Uno RX (TFMINI TX), Uno TX (TFMINI RX)

TFMini tfmini;

void setup() {

  // Step 1: Initialize hardware serial port (serial debug port)

  Serial.begin(115200);

  // wait for serial port to connect. Needed for native USB port only

  while (!Serial);

     

  Serial.println ("Initializing...");

  // Step 2: Initialize the data rate for the SoftwareSerial port

  mySerial.begin(TFMINI_BAUDRATE);

  delay(10);

  // Step 3: Initialize the TF Mini sensor

  tfmini.begin(&mySerial);    

}

void loop() {

  // Take one TF Mini distance measurement

  uint16_t dist = tfmini.getDistance();

  uint16_t strength = tfmini.getRecentSignalStrength();

  // Display the measurement

  Serial.print(dist);

  Serial.print(" cm      sigstr: ");

  Serial.println(strength);

  // Wait some short time before taking the next measurement

  delay(25);  

}
 * */

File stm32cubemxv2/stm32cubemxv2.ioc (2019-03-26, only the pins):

Mcu.UserName=STM32F427VITx
PA0/WKUP.GPIO_Label=DEC_LF_1
PA0/WKUP.Signal=S_TIM2_CH1_ETR
PA1.GPIO_Label=DEC_LF_2
PA1.Signal=S_TIM2_CH2
PA10.Signal=USB_OTG_FS_ID
PA11.Signal=USB_OTG_FS_DM
PA12.Signal=USB_OTG_FS_DP
PA13.Signal=SYS_JTMS-SWDIO
PA14.Signal=SYS_JTCK-SWCLK
PA2.Signal=USART2_TX
PA3.Signal=USART2_RX
PA6.GPIO_Label=DEC_LB_1
PA6.Signal=S_TIM3_CH1
PA7.GPIO_Label=DEC_LB_2
PA7.Signal=S_TIM3_CH2
PA8.Signal=I2C3_SCL
PA9.Signal=USB_OTG_FS_VBUS
PB0.GPIO_Label=PWM3
PB0.Signal=S_TIM3_CH3
PB1.GPIO_Label=PWM4
PB1.Signal=S_TIM3_CH4
PB10.GPIO_Label=PWM1
PB10.Signal=S_TIM2_CH3
PB11.GPIO_Label=PWM2
PB11.Signal=S_TIM2_CH4
PB3.GPIO_Label=M_RB_IN2
PB3.Signal=GPIO_Output
PB4.GPIO_Label=M_SLEEP
PB4.Signal=GPIO_Output
PB5.GPIO_Label=M_RESET
PB5.Signal=GPIO_Output
PB6.Signal=I2C1_SCL
PB7.Signal=I2C1_SDA
PB8.GPIO_Label=PWM_LIDAR
PB8.Signal=S_TIM10_CH1
PB9.GPIO_Label=PWM_FAN
PB9.Signal=S_TIM11_CH1
PC0.GPIO_Label=BAT_LVL
PC0.Signal=ADCx_IN10
PC10.Signal=UART4_TX
PC11.Signal=UART4_RX
PC12.GPIO_Label=NFAULT
PC12.Signal=GPXTI12
PC6.GPIO_Label=DEC_RB_1
PC6.Signal=S_TIM8_CH1
PC7.GPIO_Label=DEC_RB_2
PC7.Signal=S_TIM8_CH2
PC9.Signal=I2C3_SDA
PD0.GPIO_Label=LIDAR_POS_INT
PD0.Signal=GPXTI0
PD1.GPIO_Label=M_LF_IN1
PD1.Signal=GPIO_Output
PD12.GPIO_Label=DEC_RF_1
PD12.Signal=S_TIM4_CH1
PD13.GPIO_Label=DEC_RF_2
PD13.Signal=S_TIM4_CH2
PD2.GPIO_Label=M_LF_IN2
PD2.Signal=GPIO_Output
PD3.GPIO_Label=M_LB_IN1
PD3.Signal=GPIO_Output
PD4.GPIO_Label=M_LB_IN2
PD4.Signal=GPIO_Output
PD5.GPIO_Label=M_RF_IN1
PD5.Signal=GPIO_Output
PD6.GPIO_Label=M_RF_IN2
PD6.Signal=GPIO_Output
PD7.GPIO_Label=M_RB_IN1
PD7.Signal=GPIO_Output
PD8.Signal=USART3_TX
PD9.Signal=USART3_RX
PE11.GPIO_Label=TEMPERATURE
PE11.Signal=GPIO_Input
PE13.GPIO_Label=M_PWM_LF
PE13.Signal=S_TIM1_CH3
PE14.GPIO_Label=M_PWM_LB
PE14.Signal=S_TIM1_CH4
PE5.GPIO_Label=M_PWM_RF
PE5.Signal=S_TIM9_CH1
PE6.GPIO_Label=M_PWM_RB
PE6.Signal=S_TIM9_CH2
PE9.GPIO_Label=PWM_LIGHT
PE9.Signal=S_TIM1_CH1
PH0/OSC_IN.Signal=RCC_OSC_IN
PH1/OSC_OUT.Signal=RCC_OSC_OUT

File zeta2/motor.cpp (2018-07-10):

#include <Arduino.h>
#include "motor.h"

#define MAX_PWM 255

Motor::Motor(int pinA, int pinB, int enable)
{
    this->pinA = pinA;
    this->pinB = pinB;
    this->enable = enable;
    this->speed = 0;
}

void Motor::begin()
{
    pinMode(this->pinA, OUTPUT);
    pinMode(this->pinB, OUTPUT);
    pinMode(this->enable, OUTPUT);
}

void Motor::set(int speed)
{
    this->speed = speed; // keep the raw passed value to detect changes more easy

    if (speed > MAX_PWM)
        speed = MAX_PWM;
    if (speed < MAX_PWM)
        speed = -MAX_PWM;

    if (this->speed > 0)
    {
        digitalWrite(this->pinA, 0);
        digitalWrite(this->pinB, 1);
        analogWrite(this->enable, speed);
        return;
    }

    if (this->speed < 0)
    {
        digitalWrite(this->pinA, 1);
        digitalWrite(this->pinB, 0);
        analogWrite(this->enable, speed);
        return;
    }

    this->speed = 0;
    digitalWrite(this->pinA, 0);
    digitalWrite(this->pinB, 0);
    analogWrite(this->enable, 0);
}

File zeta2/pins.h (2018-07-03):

#ifndef pins_h
#define pins_h

/** Motor left */
#define PIN_ENABLE_LEFT 6
#define PIN_MOTOR_LEFT_A 11
#define PIN_MOTOR_LEFT_B 12

/** Motor right*/
#define PIN_ENABLE_RIGHT 6
#define PIN_MOTOR_RIGHT_A 5
#define PIN_MOTOR_RIGHT_B 12

/** LIDAR Stepper Motor */
#define PIN_STEPPER_CURRENT_I1 A0 // D14
#define PIN_STEPPER_CURRENT_I2 A1 // D15
#define PIN_STEPPER_DIR A2        // D16
#define PIN_STEPPER_STEP A6       // D20

/** Fan */
#define PIN_FAN A7 // D21

/** Zero Position Sensor */
#define PIN_ZEROING_SENSOR 13

/** DS18B20 Temperature Sensor - OneWire */
#define PIN_MOTOR_TEMPERATURE 2 //ADDRES: R=28 61 64 11 BD 93 D5 1

/** Analog Distance Sensor */
#define PIN_ANALOG_DISTANCE A9 // (D23)

/** TF MINI Serial Port (Serial 1) */
#define PIN_RX_TFMINI 0
#define PIN_TX_TFMINI 1

/** Port for I2C Communication to Raspberry PI - BUS 1*/
#define I2C_PI_SCL A18 // (D29)
#define I2c_PI_SDA A19 // (D30)

/** Port for I2C Communication to peripherals, e.g. GY-88 - BUS 0 */
#define I2C_PERIPHERY_SCL A5 // (D19)
#define I2c_PERIPHERY_SDA A4 // (D18)

#define SERIAL_PI_RX 9
#define SERIAL_PI_TX 10

#endif

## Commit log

2018-06-12 motor stuff
2018-06-12 more motor
2018-06-13 added fan, ino in testing mode
2018-06-14 added temperature sensor
2018-06-16 added pcb
    [new_mb_v3.fzz]
2018-06-17 new pcb version
    [led_transistor.fzz, new_mb_v6.fzz]
2018-06-17 pcb update
    [new_mb_v3.fzz, new_mb_v6.fzz, new_mb_v7.fzz]
2018-06-17 changed pcb
    [new_mb_v11.fzz, new_mb_v7.fzz]
2018-07-10 addded eagle files
    [smd_motherboard.fzz, smd_motherboard_v2.fzz, zeta2.brd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]
2018-07-24 added i2c device
    [zeta2.sch, zeta2rework.brd, zeta2rework.sch]
2018-07-26 worked on pcb, fixed stm32 layout
    [zeta2rework.brd, zeta2rework.sch]
2018-07-26 added temperature sensor to l239d, heatplate missing
    [zeta2rework.brd]
2018-07-27 worked on pcb layout -piheader wrong
    [zeta2rework.brd, zeta2rework.sch]
2018-08-01 added hall effect sensor
    [zeta2rework.brd, zeta2rework.sch]
2018-08-02 worked on layout
    [zeta2rework.brd]
2018-08-05 adde capicator for mp6500
    [zeta2rework.brd, zeta2rework.sch]
2019-02-05 added new pcb version
    [zeta2rework.brd, zeta2rework_lw.brd, zeta2rework_lw.sch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]
2019-02-10 finished pcb
    [zeta2rework_lw_v10.brd, zeta2rework_lw_v10.sch, zeta2rework_lw_v11.brd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]
2019-02-10 small changes
    [zeta2rework_lw_v18.brd]
2019-02-10 using ph for leds again
    [zeta2rework_lw_v18.brd, zeta2rework_lw_v19.brd, zeta2rework_lw_v19.sch]
2019-02-10 fixed power supply
    [zeta2rework_lw_v19.brd]
2019-02-10 added extensionn pins
    [zeta2rework_lw_v20.brd, zeta2rework_lw_v20.sch]
2019-02-12 removed l293d transistors
    [zeta2rework_lw_v20_wo_transistor.brd, zeta2rework_lw_v20_wo_transistor.sch]
2019-02-17 added new lidar pcb, added new version of mainboard, added stls for mb and lidar pcb
    [lidar.brd, lidar.sch, lidar.stl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]
2019-03-05 working on fixes of pcb
    [voltage_control.brd, voltage_control.sch, zeta2rework_lw_v22_wo_transistor.brd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]
2019-03-11 version 3 of pcb should be finihsed now
    [zeta2rework_lw_v23_fixes.brd, zeta2rework_lw_v23_fixes.sch, zeta2rework_lw_v24_fixes.brd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]
2019-03-12 moved pwr in, added smd LED
    [zeta2rework_lw_v26_fixes_wompu.brd, zeta2rework_lw_v26_fixes_wompu.sch]
2019-03-15 changed to new parts
    [zeta2rework_lw_v27_rework.brd, zeta2rework_lw_v27_rework.sch]
2019-03-18 using stm32f4, fixed pin settings, added cubemx
    [zeta2rework_lw_v27_rework.brd, zeta2rework_lw_v27_rework.sch]
2019-03-19 added usb
    [zeta2rework_lw_v27_rework.brd, zeta2rework_lw_v27_rework.sch]
2019-03-23 working on new pcb layout
    [zeta2rework_lw_v27_rework.brd, zeta2rework_lw_v27_rework.sch, zeta2rework_lw_v28_rework.brd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]
2019-03-26 progress on traces
    [zeta2rework_lw_v32_rework.sch, zeta2rework_lw_v33_rework.brd, zeta2rework_lw_v33_rework.sch]
2019-03-27 connected power supply
    [zeta2rework_lw_v33_rework.brd, zeta2rework_lw_v34_rework.brd, zeta2rework_lw_v34_rework.sch]

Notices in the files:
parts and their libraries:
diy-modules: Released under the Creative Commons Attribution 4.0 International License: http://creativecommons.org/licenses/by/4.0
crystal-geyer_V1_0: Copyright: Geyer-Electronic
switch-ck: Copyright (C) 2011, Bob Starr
